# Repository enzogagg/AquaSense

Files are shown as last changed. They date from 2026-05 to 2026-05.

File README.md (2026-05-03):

# 🌊 AquaSense: Intelligent Water Quality Monitoring






**AquaSense** is a comprehensive IoT solution dedicated to real-time water quality monitoring. This project showcases cross-disciplinary expertise combining **Software Engineering (C++/YAML)**, **Analog Electronics**, and **Mechanical Design (3D CAD)**.

---

## 🌟 Project Highlights

- **Multi-Framework Architecture**: Native support for **PlatformIO (Pure C++)** for low-level control, and **ESPHome** for seamless Home Automation (Home Assistant) integration.
- **Advanced Signal Processing**: Implementation of 3rd-degree polynomial regression algorithms for TDS (Total Dissolved Solids) and Turbidity sensors to ensure data accuracy.
- **Industrial Design**: Custom-designed, 3D-printed enclosures and sensor mounts optimized for durability and easy maintenance in aquatic environments.
- **Mission-Critical Safety**: Integrated hardware and software "Fail-safe" logic for pump control to prevent flooding or dry running.

---

## 🛠️ Technical Expertise

### 1. Electronics & Sensors
The system is built around the **ESP32** microcontroller, managing multiple data protocols:
- **OneWire**: High-precision communication with the DS18B20 thermal probe.
- **ADC (Analog to Digital Converter)**: Optimized reading of turbidity and TDS analog values with software attenuation for maximum 3.3V precision.
- **Relay Control**: High-power actuator management with built-in duty cycle protection.

### 2. Algorithms & Mathematics
To ensure laboratory-grade reliability, the firmware processes raw analog signals into meaningful data:
- **TDS Conversion**: Utilizes a 3rd-degree polynomial regression curve to compensate for the non-linear response of analog TDS probes.
- **Turbidity Calibration**: Scalable linear calibration to provide precise NTU (Nephelometric Turbidity Units) readings.

### 3. Mechanical Design (CAD)
Source files (FreeCAD/STEP) provide a modular and industrial enclosure system:
- **Modular Controller Hub**: A multi-part assembly including a main box with integrated cooling vents and dedicated internal supports for electronics.
- **Branded Top Cover**: Custom embossed branding with a sleek, minimalist aesthetic.
- **Versatile Mounting**: Features an `eccentric bolt` system for secure attachment to various aquatic environments (tanks, sumps, etc.).
- **Optimized Sensor Kits**: Protective mounts for TDS and Turbidity probes designed to minimize interference with water flow.

---

## 🔌 Circuitry & Schematics

The system architecture ensures galvanic isolation for the actuators and precise signal levels for the sensors. Below is the logical wiring diagram:

```mermaid
graph LR
    %% Définition des couleurs
    classDef power fill:#e74c3c,stroke:#c0392b,stroke-width:2px,color:#fff;
    classDef esp fill:#3498db,stroke:#2980b9,stroke-width:3px,color:#fff;
    classDef component fill:#ecf0f1,stroke:#bdc3c7,stroke-width:2px;
    classDef shifter fill:#f39c12,stroke:#e67e22,stroke-width:2px,color:#fff;

    %% Composants Principaux
    Alim[Bloc Alimentation 5V 5A]
    ESP[ESP32 Dev Board]

    %% Groupes logiques
    subgraph Bloc_Puissance [Circuit de Puissance 5V]
        Relais[Module Relais 1 Canal]
        Pompe[Pompe à Membrane 5V]
    end

    subgraph Interface_Isolation [Sécurité des Signaux]
        Shifter[Level Shifter 3.3V vers 5V]
    end

    subgraph Capteurs_33V [Capteurs 3.3V]
        Niveau[Niveau XKC-Y25]
        Temp[Température DS18B20]
        TDS[Capteur TDS]
        Turb[Capteur Turbidité]
    end

    %% --- CÂBLAGE ALIMENTATION ---
    Alim -- "+5V" --> ESP
    Alim -- "+5V" --> Relais
    Alim -- "+5V (HV)" --> Shifter

    %% --- CÂBLAGE MASSE ---
    Alim -- "GND" --> ESP
    Alim -- "GND" --> Relais
    Alim -- "GND" --> Pompe
    Alim -- "GND" --> Shifter

    %% --- LOGIQUE POMPE ---
    ESP -- "3.3V (LV1) -> GPIO 33" --> Shifter
    Shifter -- "5V (HV1)" --> Relais
    Relais -- "NO (+5V)" --> Pompe

    %% --- DISTRIBUTION 3.3V ---
    ESP -- "3.3V" --> Shifter
    ESP -- "3.3V" --> Niveau
    ESP -- "3.3V" --> Temp
    ESP -- "3.3V" --> TDS
    ESP -- "3.3V" --> Turb

    ESP -- "GND" --> Niveau
    ESP -- "GND" --> Temp
    ESP -- "GND" --> TDS
    ESP -- "GND" --> Turb

    %% --- DATA SIGNALS ---
    Niveau -- "GPIO 18" --> ESP
    Temp -- "GPIO 19 (Pull-up 4.7kΩ)" --> ESP
    TDS -- "GPIO 35" --> ESP
    Turb -- "GPIO 34" --> ESP

    %% --- APPLICATION DES STYLES ---
    class Alim power;
    class ESP esp;
    class Relais,Pompe,Niveau,Temp,TDS,Turb component;
    class Shifter shifter;
```

---

## 🔧 Assembly & Hardware

The AquaSense enclosure is designed for durability and ease of maintenance. 

### 1. Hardware Requirements
- **Fasteners**: M3 Stainless Steel screws are used throughout to prevent corrosion in humid environments.
- **Mounting**: Brass heat-set inserts can be used for the internal supports to allow repeated assembly/disassembly without stripping the plastic.
- **Connectivity**: A panel-mount USB-C extension provides a robust external power interface while keeping the ESP32 protected inside.

### 2. Assembly Steps
1.  **Preparation**: Install M3 heat-set inserts (optional) into the `Main Controller Box`.
2.  **Electronics**: Secure the ESP32 Dev Board onto the `Electronic Card Support` tray.
3.  **Integration**: Slide the electronic tray into the main box and secure the cables through the dedicated ports.
4.  **Sealing**: Install the `Back Cover` for cable management and the `Top Cover` for final protection.
5.  **Deployment**: Use the `Eccentric Bolt` system to clamp the unit onto your tank or sump.

For a full list of components, see the [Bill of Materials (BOM)](BOM.md).

---

## 📂 Project Structure

```bash
├── 📂 firmware           # Firmware source code
│   ├── 📂 cpp            # Pure C++ Firmware (PlatformIO)
│   └── 📂 esphome        # Infrastructure as Code (YAML)
├── 📂 cad                # CAD Files (STL, STEP, FCStd)
├── 📂 assets            # Project images and diagrams
├── 📂 .github           # CI/CD Pipelines
└── LICENSE              # MIT License
```

---

## ⚙️ Installation & Deployment

### Option A: ESPHome (Recommended for Home Assistant)
1. Install ESPHome: `pip install esphome`
2. Copy `firmware/esphome/secrets.yaml.example` to `firmware/esphome/secrets.yaml` and fill in your credentials.
3. Deploy: `esphome run firmware/esphome/aquasense.yaml`

### Option B: PlatformIO (For C++ Development)
1. Open the `firmware/cpp` folder in VS Code with PlatformIO.
2. Compile and flash to your ESP32.

---

## 📊 Gallery & Showcase

| Industrial Enclosure | Branded Top Cover | Home Assistant Dashboard |
| :---: | :---: | :---: |
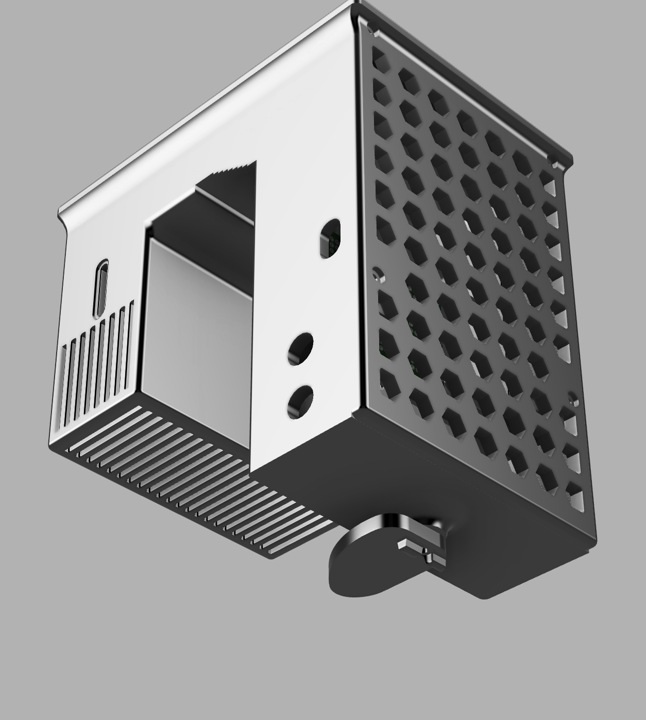
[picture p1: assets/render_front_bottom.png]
Front View
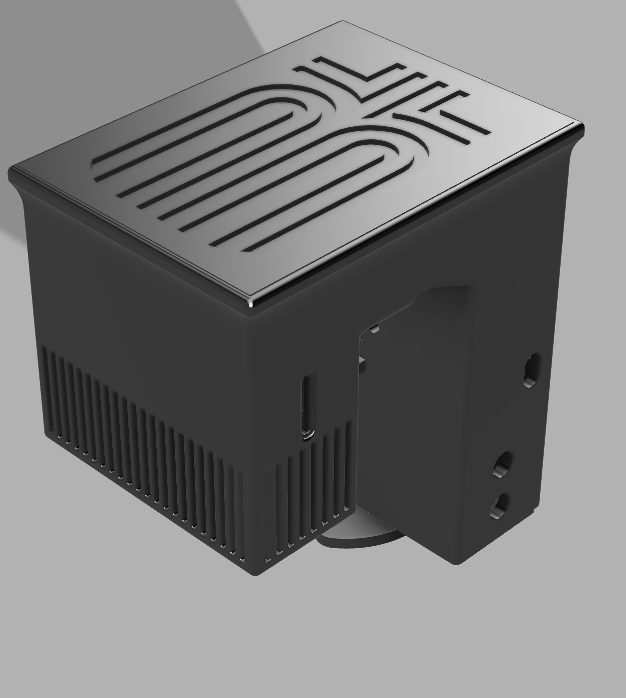
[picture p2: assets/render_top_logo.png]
Top View
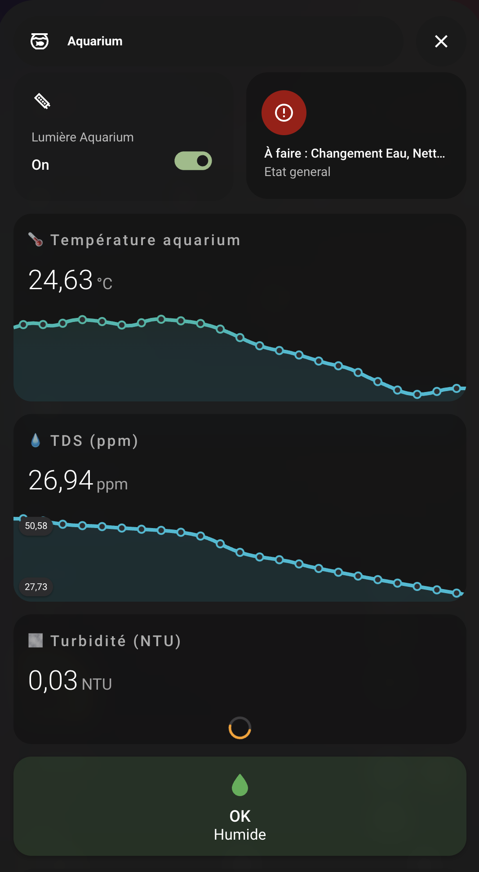
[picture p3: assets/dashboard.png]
Dashboard
|  |  |  |

---

## 📝 License

This project is released under the **MIT License**. Feel free to use, modify, and distribute it for your own projects.

---

## 👤 Contact & Portfolio

**Enzo Gaggiotti**
- **Specialization**: IoT, Infrastructure, DevSecOps.
- [GitHub Profile](https://github.com/enzogagg)

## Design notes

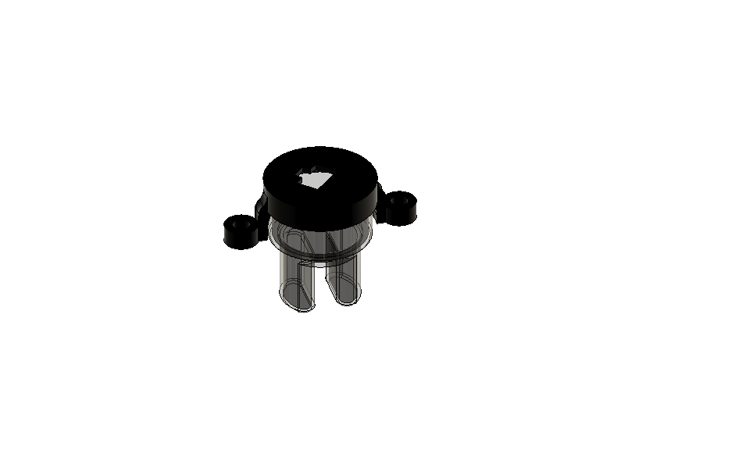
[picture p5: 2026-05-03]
cad/Model 3D pièce/Turbidity Sensor/Turbidity Sensor v1.png

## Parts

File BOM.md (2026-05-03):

# Bill of Materials (BOM) - AquaSense

This document lists all the components required to build the AquaSense monitoring system.

## 1. Electronics

| Component | Description | Qty | Note |
| :--- | :--- | :---: | :--- |
| **ESP32 DevKit V1** | Main Microcontroller (WiFi/BT) | 1 | |
| **DS18B20 Probe** | Waterproof Temperature Sensor | 1 | OneWire protocol |
| **Analog TDS Sensor** | Total Dissolved Solids sensor | 1 | Includes adapter board |
| **Turbidity Sensor** | Analog Turbidity Sensor | 1 | Includes adapter board |
| **Liquid Level Sensor** | XKC-Y25 Photoelectric | 1 | Non-contact level sensing |
| **Level Shifter** | 4-channel 3.3V <-> 5V | 1 | For Relay/Pump logic |
| **Relay Module** | 5V Single Channel Relay | 1 | For pump control |
| **Resistor 4.7kΩ** | Pull-up resistor for OneWire | 1 | For DS18B20 |
| **Power Supply** | 5V 5A DC Adapter | 1 | High current for pump/relays |

## 2. Mechanical & 3D Printing

| Part | Material | Qty | Note |
| :--- | :--- | :---: | :--- |
| **Main Controller Box** | PETG / PLA | 1 | Industrial design with cooling vents |
| **Top Cover** | PETG / PLA | 1 | Features embossed branding |
| **Back Cover** | PETG / PLA | 1 | Cable management and port access |
| **Electronic Card Support** | PETG / PLA | 1 | Internal tray for ESP32 mounting |
| **Eccentric Bolt** | PETG / PLA | 1 | Custom clamping mechanism |
| **Sensor Holder (TDS)** | PETG / PLA | 1 | Custom mount |
| **Sensor Holder (Turbidity)** | PETG / PLA | 1 | Custom mount |
| **Temperature Probe Clip** | PETG / PLA | 1 | |

## 3. Hardware & Fasteners

| Item | Type | Qty | Note |
| :--- | :--- | :---: | :--- |
| **M3 Screws** | Stainless Steel | 6-8 | For covers and internal mounts |
| **M3 Heat-Set Inserts** | Brass | 6-8 | Optional - For superior durability |
| **USB-C Extension** | Panel Mount | 1 | (As seen in CAD) For external power |

## 4. Miscellaneous

- Jumper Wires (Dupont) or Custom PCB
- Waterproof glands (for sensor cables)
- Solder & Soldering Iron
- **3D Printing Filament**: PETG is strongly recommended for its water resistance and mechanical strength.

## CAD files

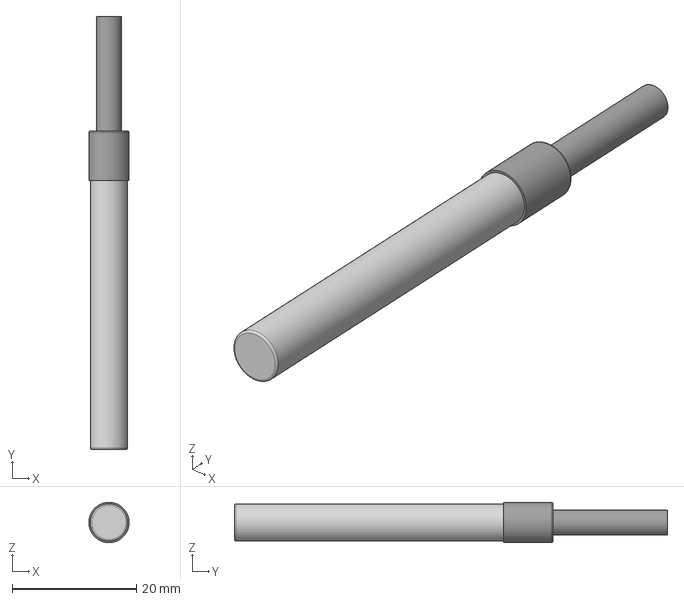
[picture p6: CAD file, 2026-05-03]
cad/Model 3D pièce/DS18B20 temperature Sensor/DS18B20.stp
6.49 x 69.7 x 6.50 mm

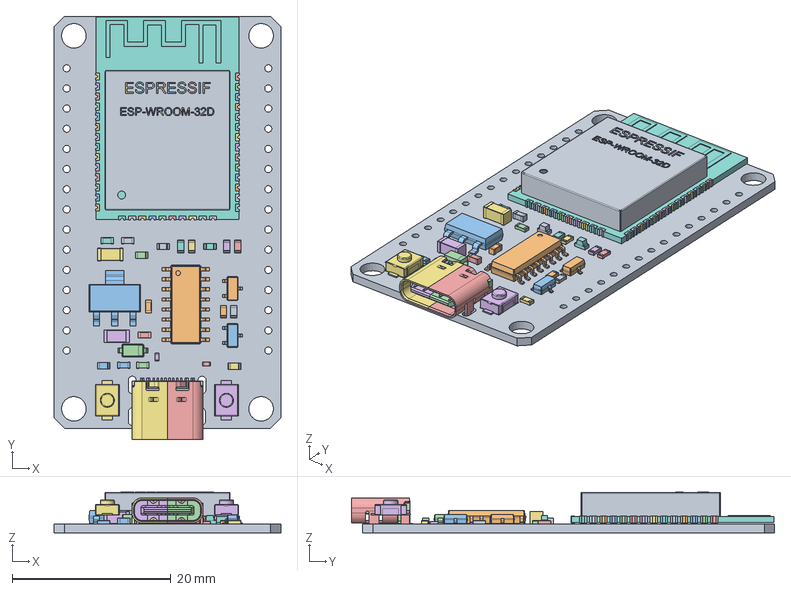
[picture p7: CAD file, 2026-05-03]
cad/Model 3D pièce/Esp32/esp32_wroom_32D_kitV1.FCStd
28.6 x 53.3 x 5.15 mm
PCB
SOIC_16_39x99mm_P127mm
SOT_223
USB_C_Receptacle_16P_TopMnt_Horizontal_GCT_USB4105-xx-A
USB_C_Receptacle_16P_TopMnt_Horizontal_GCT_USB4105-xx-A001
USB_C_Receptacle_16P_TopMnt_Horizontal_GCT_USB4105-xx-A002
USB_C_Receptacle_16P_TopMnt_Horizontal_GCT_USB4105-xx-A003
USB_C_Receptacle_16P_TopMnt_Horizontal_GCT_USB4105-xx-A004
USB_C_Receptacle_16P_TopMnt_Horizontal_GCT_USB4105-xx-A005
USB_C_Receptacle_16P_TopMnt_Horizontal_GCT_USB4105-xx-A006
USB_C_Receptacle_16P_TopMnt_Horizontal_GCT_USB4105-xx-A007
USB_C_Receptacle_16P_TopMnt_Horizontal_GCT_USB4105-xx-A008
USB_C_Receptacle_16P_TopMnt_Horizontal_GCT_USB4105-xx-A009
USB_C_Receptacle_16P_TopMnt_Horizontal_GCT_USB4105-xx-A010
USB_C_Receptacle_16P_TopMnt_Horizontal_GCT_USB4105-xx-A011
USB_C_Receptacle_16P_TopMnt_Horizontal_GCT_USB4105-xx-A012
USB_C_Receptacle_16P_TopMnt_Horizontal_GCT_USB4105-xx-A013
USB_C_Receptacle_16P_TopMnt_Horizontal_GCT_USB4105-xx-A014
USB_C_Receptacle_16P_TopMnt_Horizontal_GCT_USB4105-xx-A015
USB_C_Receptacle_16P_TopMnt_Horizontal_GCT_USB4105-xx-A016
USB_C_Receptacle_16P_TopMnt_Horizontal_GCT_USB4105-xx-A017
USB_C_Receptacle_16P_TopMnt_Horizontal_GCT_USB4105-xx-A018
USB_C_Receptacle_16P_TopMnt_Horizontal_GCT_USB4105-xx-A019
USB_C_Receptacle_16P_TopMnt_Horizontal_GCT_USB4105-xx-A020
USB_C_Receptacle_16P_TopMnt_Horizontal_GCT_USB4105-xx-A021
USB_C_Receptacle_16P_TopMnt_Horizontal_GCT_USB4105-xx-A022
USB_C_Receptacle_16P_TopMnt_Horizontal_GCT_USB4105-xx-A023
USB_C_Receptacle_16P_TopMnt_Horizontal_GCT_USB4105-xx-A024
USB_C_Receptacle_16P_TopMnt_Horizontal_GCT_USB4105-xx-A025
USB_C_Receptacle_16P_TopMnt_Horizontal_GCT_USB4105-xx-A026
USB_C_Receptacle_16P_TopMnt_Horizontal_GCT_USB4105-xx-A027
USB_C_Receptacle_16P_TopMnt_Horizontal_GCT_USB4105-xx-A028
USB_C_Receptacle_16P_TopMnt_Horizontal_GCT_USB4105-xx-A029
USB_C_Receptacle_16P_TopMnt_Horizontal_GCT_USB4105-xx-A030
USB_C_Receptacle_16P_TopMnt_Horizontal_GCT_USB4105-xx-A031
USB_C_Receptacle_16P_TopMnt_Horizontal_GCT_USB4105-xx-A032
USB_C_Receptacle_16P_TopMnt_Horizontal_GCT_USB4105-xx-A033
USB_C_Receptacle_16P_TopMnt_Horizontal_GCT_USB4105-xx-A034
USB_C_Receptacle_16P_TopMnt_Horizontal_GCT_USB4105-xx-A035
LED_0603_D2
LED_0603_PWR
SOT_23_1
SOT_23_002
D_SOD_123
R_0603_
R_0603_001
R_0603_002
R_0603_003
R_0603_004
R_0603_005
R_0603_006
R_0603_007
R_0402_001
R_0402_002
R_0603_008
C_0603_
C_0603_001
C_0603_002
C_0603_003
C_0603_004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

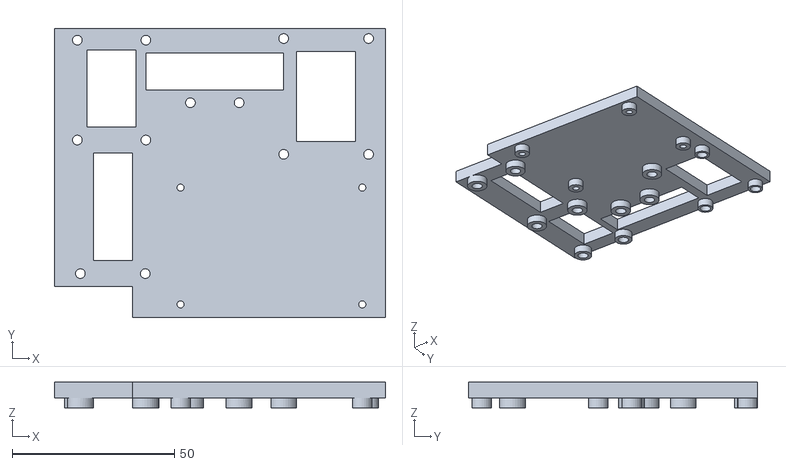
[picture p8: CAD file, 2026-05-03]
cad/STL/electronique card support.stl
102.0 x 89.0 x 8.00

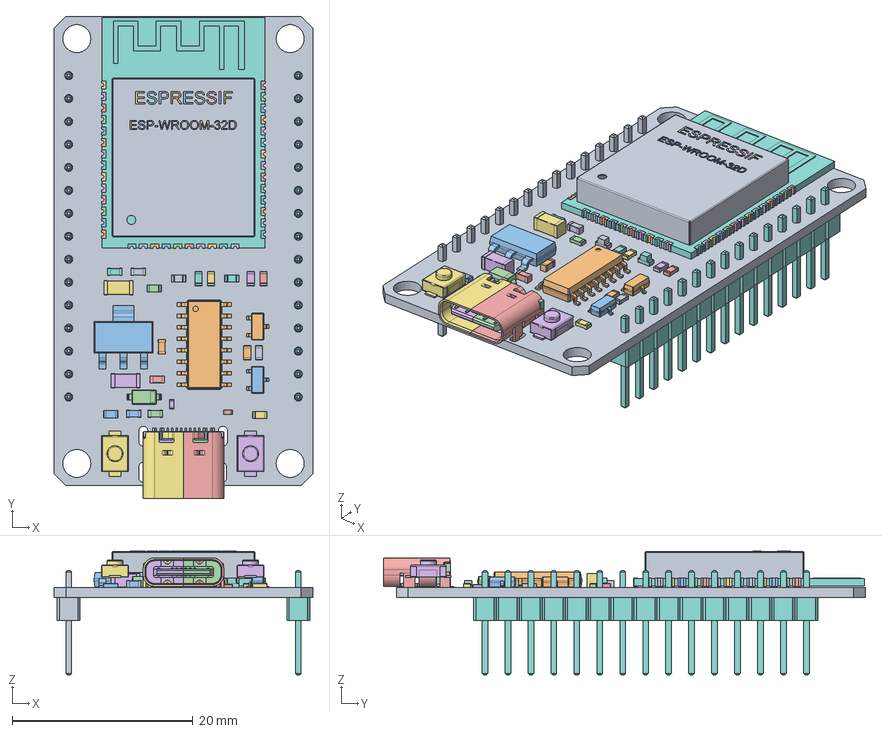
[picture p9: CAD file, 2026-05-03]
cad/Model 3D pièce/Esp32/esp32_wroom_32D_kitV1_wph.FCStd
28.6 x 53.3 x 13.7 mm
PCB
SOIC_16_39x99mm_P127mm
SOT_223
USB_C_Receptacle_16P_TopMnt_Horizontal_GCT_USB4105-xx-A
USB_C_Receptacle_16P_TopMnt_Horizontal_GCT_USB4105-xx-A001
USB_C_Receptacle_16P_TopMnt_Horizontal_GCT_USB4105-xx-A002
USB_C_Receptacle_16P_TopMnt_Horizontal_GCT_USB4105-xx-A003
USB_C_Receptacle_16P_TopMnt_Horizontal_GCT_USB4105-xx-A004
USB_C_Receptacle_16P_TopMnt_Horizontal_GCT_USB4105-xx-A005
USB_C_Receptacle_16P_TopMnt_Horizontal_GCT_USB4105-xx-A006
USB_C_Receptacle_16P_TopMnt_Horizontal_GCT_USB4105-xx-A007
USB_C_Receptacle_16P_TopMnt_Horizontal_GCT_USB4105-xx-A008
USB_C_Receptacle_16P_TopMnt_Horizontal_GCT_USB4105-xx-A009
USB_C_Receptacle_16P_TopMnt_Horizontal_GCT_USB4105-xx-A010
USB_C_Receptacle_16P_TopMnt_Horizontal_GCT_USB4105-xx-A011
USB_C_Receptacle_16P_TopMnt_Horizontal_GCT_USB4105-xx-A012
USB_C_Receptacle_16P_TopMnt_Horizontal_GCT_USB4105-xx-A013
USB_C_Receptacle_16P_TopMnt_Horizontal_GCT_USB4105-xx-A014
USB_C_Receptacle_16P_TopMnt_Horizontal_GCT_USB4105-xx-A015
USB_C_Receptacle_16P_TopMnt_Horizontal_GCT_USB4105-xx-A016
USB_C_Receptacle_16P_TopMnt_Horizontal_GCT_USB4105-xx-A017
USB_C_Receptacle_16P_TopMnt_Horizontal_GCT_USB4105-xx-A018
USB_C_Receptacle_16P_TopMnt_Horizontal_GCT_USB4105-xx-A019
USB_C_Receptacle_16P_TopMnt_Horizontal_GCT_USB4105-xx-A020
USB_C_Receptacle_16P_TopMnt_Horizontal_GCT_USB4105-xx-A021
USB_C_Receptacle_16P_TopMnt_Horizontal_GCT_USB4105-xx-A022
USB_C_Receptacle_16P_TopMnt_Horizontal_GCT_USB4105-xx-A023
USB_C_Receptacle_16P_TopMnt_Horizontal_GCT_USB4105-xx-A024
USB_C_Receptacle_16P_TopMnt_Horizontal_GCT_USB4105-xx-A025
USB_C_Receptacle_16P_TopMnt_Horizontal_GCT_USB4105-xx-A026
USB_C_Receptacle_16P_TopMnt_Horizontal_GCT_USB4105-xx-A027
USB_C_Receptacle_16P_TopMnt_Horizontal_GCT_USB4105-xx-A028
USB_C_Receptacle_16P_TopMnt_Horizontal_GCT_USB4105-xx-A029
USB_C_Receptacle_16P_TopMnt_Horizontal_GCT_USB4105-xx-A030
USB_C_Receptacle_16P_TopMnt_Horizontal_GCT_USB4105-xx-A031
USB_C_Receptacle_16P_TopMnt_Horizontal_GCT_USB4105-xx-A032
USB_C_Receptacle_16P_TopMnt_Horizontal_GCT_USB4105-xx-A033
USB_C_Receptacle_16P_TopMnt_Horizontal_GCT_USB4105-xx-A034
USB_C_Receptacle_16P_TopMnt_Horizontal_GCT_USB4105-xx-A035
LED_0603_D2
LED_0603_PWR
SOT_23_1
SOT_23_002
D_SOD_123
R_0603_
R_0603_001
R_0603_002
R_0603_003
R_0603_004
R_0603_005
R_0603_006
R_0603_007
R_0402_001
R_0402_002
R_0603_008
C_0603_
C_0603_001
C_0603_002
C_0603_003
C_0603_004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

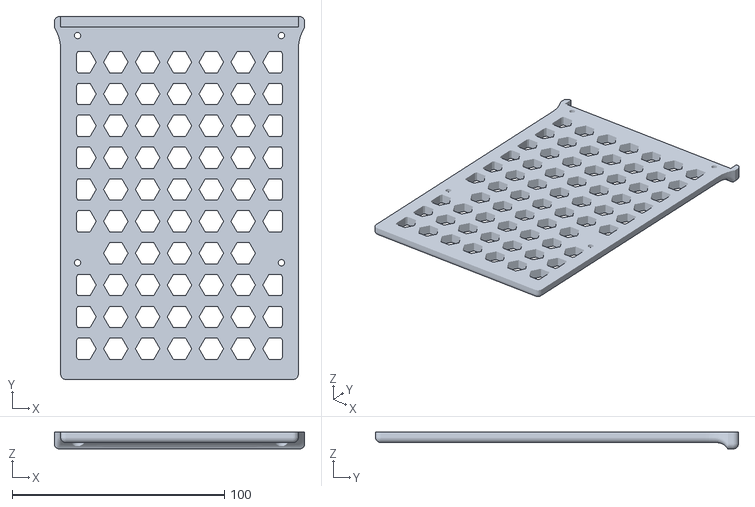
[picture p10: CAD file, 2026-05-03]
cad/STL/back cover.stl
118.0 x 171.0 x 8.00

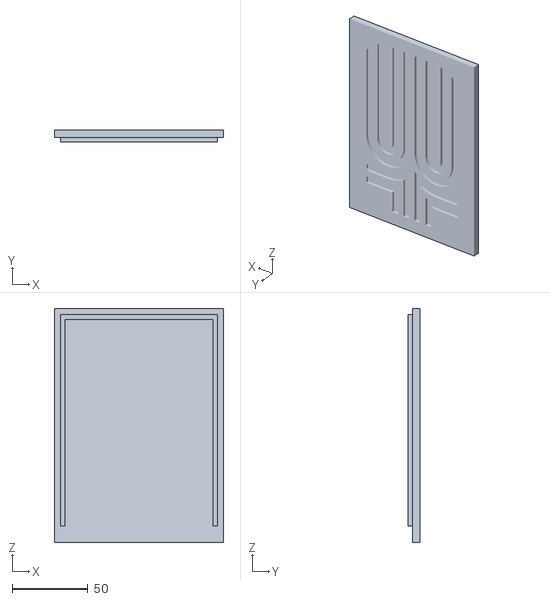
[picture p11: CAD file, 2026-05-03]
cad/STL/top cover.stl
111.8 x 8.00 x 154.4

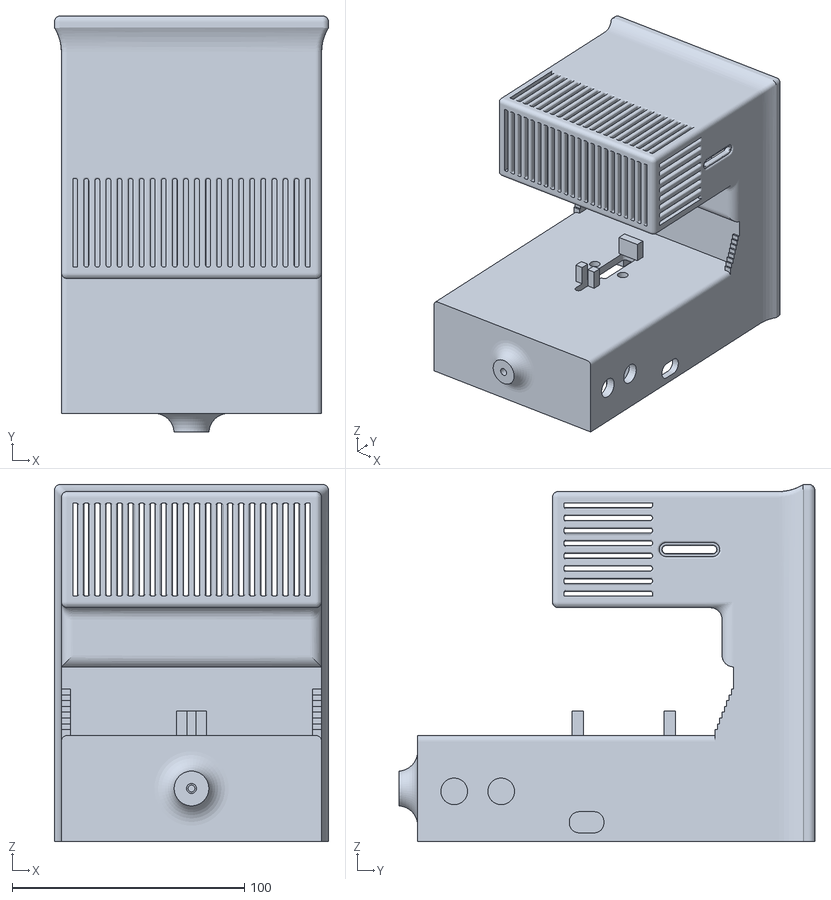
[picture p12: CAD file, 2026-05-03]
cad/STL/box aquasense.stl
118.0 x 179.0 x 153.6

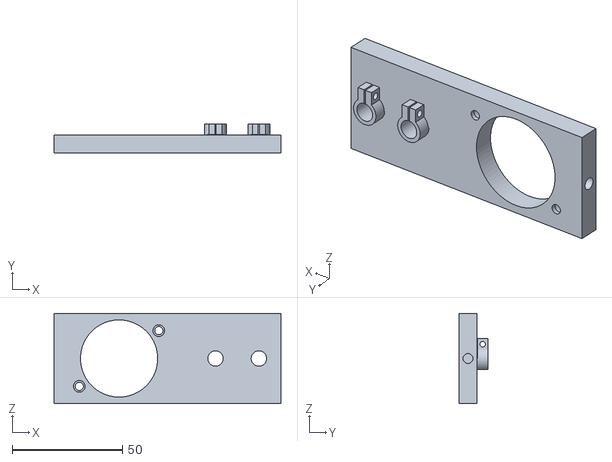
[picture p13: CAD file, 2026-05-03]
cad/STL/support sensor.stl
103.0 x 13.0 x 41.0

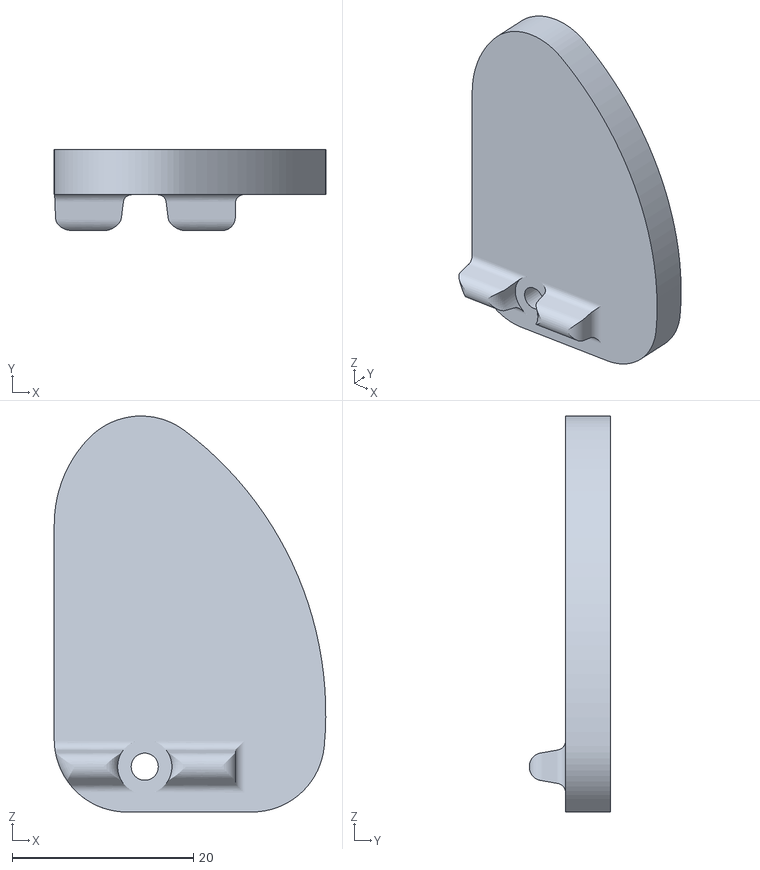
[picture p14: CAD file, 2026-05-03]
cad/STL/eccentric bolt.stl
30.0 x 9.00 x 43.7

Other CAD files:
cad/Model 3D pièce/DS18B20 temperature Sensor/DS18B20.prt
cad/Model 3D pièce/Turbidity Sensor/Turbidity Sensor v1.f3d

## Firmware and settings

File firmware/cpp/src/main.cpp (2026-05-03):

#include <Arduino.h>
#include "temperature.h"
#include "tds.h"
#include "level.h"
#include "turbidity.h"
#include "relay.h"

unsigned long lastRelayToggle = 0;
const unsigned long RELAY_TOGGLE_INTERVAL = 3000;  // Bascule toutes les 3 secondes

void setup() {
    Serial.begin(115200);
    delay(1000);
    Serial.println("\n\n=== Démarrage du système ===");
    initTemperatureSensor();
    initTdsSensor();
    initLevelSensor();
    initTurbiditySensor();
    initRelay();
}

void loop() {
    // Test du relais : basculer toutes les 3 secondes
    unsigned long currentMillis = millis();
    if (currentMillis - lastRelayToggle >= RELAY_TOGGLE_INTERVAL) {
        lastRelayToggle = currentMillis;
        toggleRelay();
    }

    float tempC = readTemperatureC();
    float tds = readTdsValue(tempC);
    float turbidity = readTurbidityNTU();
    Serial.print("Température: ");
    Serial.print(tempC);
    Serial.println(" °C");
    Serial.print("TDS Value: ");
    Serial.print(tds, 0);
    Serial.println(" ppm");
    Serial.print("Turbidité: ");
    Serial.print(turbidity, 2);
    Serial.println(" NTU");
    if (isLiquidDetected()) {
        Serial.println("Liquide détecté !");
    } else {
        Serial.println("Pas de liquide.");
    }
    delay(1000);
}

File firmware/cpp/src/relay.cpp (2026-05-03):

#include <Arduino.h>
#include "relay.h"

void initRelay() {
    pinMode(RELAY_PIN, OUTPUT);
    digitalWrite(RELAY_PIN, LOW);
    Serial.println("Relais initialisé sur PIN " + String(RELAY_PIN));
}

void writeRelayLevel(bool highLevel) {
    digitalWrite(RELAY_PIN, highLevel ? HIGH : LOW);
    delay(2);
    Serial.print("GPIO");
    Serial.print(RELAY_PIN);
    Serial.print(" = ");
    Serial.println(digitalRead(RELAY_PIN) == HIGH ? "HIGH" : "LOW");
}

void enableRelay() {
    writeRelayLevel(true);
    Serial.println("Relais ACTIVÉ");
}

void disableRelay() {
    writeRelayLevel(false);
    Serial.println("Relais DÉSACTIVÉ");
}

void toggleRelay() {
    int currentState = digitalRead(RELAY_PIN);
    writeRelayLevel(currentState == LOW);
    Serial.println(currentState == LOW ? "Relais ACTIVÉ" : "Relais DÉSACTIVÉ");
}

int getRelayState() {
    return digitalRead(RELAY_PIN);
}

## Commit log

2025-09-20 [ADD] code for tds sensor
2025-09-20 [ADD] code for level sensor
2025-09-20 [ADD] code for temperature sensor
2025-09-20 [ADD] code for turbidity sensor
2025-09-20 [ADD] plateformio.ini et main to execute code on ESP32
2026-05-03 [UPDATE] Project structure refactoring and documentation enhancement
    [DS18B20.prt, DS18B20.stp, Turbidity Sensor v1.f3d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]
